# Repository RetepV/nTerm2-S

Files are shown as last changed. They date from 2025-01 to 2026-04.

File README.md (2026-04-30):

# nTerm2-S

> [!IMPORTANT]
> I have permanently decided to drop the CP2102 in favor of the FT231 as a USB<->Serial bridge. The CP2102 is just near impossible to solder with a soldering iron, and it was one of my objectives to not have to use hot air. As the rest of the design design is basically still the same, I decided to freeze this repository, keeping it like it is for whoever is interested, and start a new repository for the FT231 version. The design is working: if you make a board it should work, mine does.\
> \
> However, do note that I decided to move to the FT231 already before I made boards with the ESD USB protection circuit USBLC6-2SC6. It's in the latest design files here, but no boards were made and it has not been tested. However, that circuit is so uncomplicated, that I'm sure it will work fine. In worst case you can leave out the USBLC6-2SC6 and just connect pins 1-6 and 3-4. However, without ESD protection, I would suggest to connect the nTerm2-S through a cheap USB hub. No sense in jeopardising your USB ports.\
> \
> Also, I decided to add an RTC to nTerm2-S, and that's only in the FT231 version.\
> \
> Long story short, have look here for continuation of this project: https://github.com/RetepV/nTerm2-S-FT231

My rendition of the uTerm2-S by Just4Fun (https://hackaday.io/project/181583-uterm2-s-a-multi-emulation-color-rs232-terminal). This one is in SMD, and I hopefully made it easily hand-solderable for everyone (with maybe the exception of the CP2102). Obviously the 'n' in nTerm stands for 'nano.' :P

The nTerm2-S has a slightly more usable form the uTerm2-S, I think. Smaller and a little more usable when sitting permanently on a desk. And as an extra, it can switch between normal and cross (null-modem) from the software so that you wil never have to search for that null-modem cable ever again. It can also switch between RTS/CTS or DTR/DSR handshaking.

Supports RxD/TxD with RTS/CTS. Also supports DTR/DSR in a way. It is possible to switch the RTS/CTS lines to the DTR/DSR lines, using the ESP32's RTS/CTS support to manage the DTR/DSR. It's not really DTR/DSR, but as the ESP32 is a plenty fast enough DTE and only the DCE might be slow, it will work most of the times.

The nTerm2-S is ultimately based on the FABGL library and board design from Fabrizio Di Vittori. http://www.fabglib.org. However, I skipped Fabrizio's implementation and based my design on Just4Fun's uTerm2-S. https://j4f.info/uterm2-s

THIS IS A WORK IN PROGESS! I.E. UNLESS STATED AS WORKING, ASSUME THAT IT DOES NOT WORK! NO FIRMWARE HAS BEEN TESTED YET, AND AS THERE ARE SMALL DIFFERENCES IN GPIO ASSIGNMENTS, I DON'T EXPECT THE DEFAULT FABGL EXAMPLES TO WORK WITHOUT TWEAKS.

<sub><s>NOTE: The relay circuit with the bistable relays is directly out of the OMRON databook, and it allows me to switch the relay but use only power when switching (and some losses through the 470 resistor when switched on: 7mA continuous, which is a huge of a lot better than 30mA continuous when using a normal relay). That circuit sources the power from the input, which is connected to a GPIO. ESP32 GPIO pins can source 40mA and sink 28mA. According to the datasheet, the relay needs 100mW of power to switch. At 3V, that is 33mA, but we use 3.3V, so some 30mA. So when switching 'on', the ESP32 will need to source 30mA and settle at some 7mA (all theoretically, be advised). That is quite a lot, but still within spec. The ESP32 does not have to sink much, as the reverse current will go through the diode directly to ground.</s><sub>

<sub>It turned out that the ESP32 was not able to source enough power after all, so I have had to change the circuit somewhat. Now all the necessary power comes from the 5V Vbus and is switched through another transistor. I couldn't properly measure the current draw from the ESP32's GPIO port, but it looked as if it was some 4mA.</sub>

<sub>Progress! I received my fuses and did some real measurements. I used 3.3V, BAT45 (commit says 1N4148, but I was mistaken, they are BAT45's), BC337, 220u and 470 ohm on my bread board, and measured about 14mA max when switching, and 6.8mA continuous. I expected more than 14mA when switching, but maybe this relay is better than the specs? In any case, I decided to experiment with the C and R. I upped the C to 470uF, which seemed to make the switching more reliable. But more importantly, I increased the resistor in steps to see what the result would be. And found that I could go up to at least 3K9 before the switching would become unreliable. 10K was clearly too much, and I didn't try anything in between 3K9 and 10K. With 3K9, 0.88mA is drawn, and I find that good enough. The low current power led uses 3mA, and I keep that on all the time. 1mA is fine.</sub>

<sub>Created the gerbers for v0.1 and sent out to JLPCB. Jeez, it's cheap. 11 euro for 5 boards. Still had a bunch of warnings from the pins/vias of the USB-C connector and ESP32 footprints that I just could not resolve. Decided to take my chances, and JLCPCB accepted the gerbers and has actually already finished and posted the boards. So I expect the boards to be here in a few days. In the mean time, I've been doing some basic work and redesign for a version 2 of the nTerm2-S, with an SD card slot and psram, to make it more versatile (e.g. PC emulation). However, let's get this first version to work first, the objective is to have a terminal with software switchable null-modem.</sub>

<sub>After my v0.1 boards arrived I built one up. I did it in stages, starting with the CP2102 and then the power (I use the CP2102 in bus-powered mode). After much cursing, I got the CP2012 straight on the pads and it looked good under the microscope. I then added the power supply components and the USB-C port. No ESD protection yet. Doublechecked everything 10 times under the microscope, got out an old cheap USB hub (better to blow up the hub than my Macbook's port) and plugged the nTerm in. And Windows detected the CP2102 immediately, installed the drivers, and... success #1 was there!</sub>

<sub>I then added the ESP32. Could update its firmware. Success #2! Soldered the video DAC and VGA port (and fixed the ESP32). Success #3: we have video! Then populated the keyboard and mouse circuits. Success #4! After playing some Space Invaders, I populated the MAX3232 and hardwired the Rx and Tx together to do a loopback test. And we had success #5!</sub>

<sub>Then the problems started. After populating the relay circuits, I could not get them to switch. After lots of measuring and experimenting with an oscilloscope, I could only conclude that the ESP32 was simply not able to source a high enough voltage and that all my calculations and experiments apparently had been wrong. The switching voltage of the relay is 3V. But I found that the ESP32, in my setting, delivered only some 3.15V, and that goes through the BAT43W diode. The diode has a low voltage drop, but it's still something like 0.55V or more at 30mA, and that brings the operating voltage down to 2.61V. Switching one way (with a 1 on the GPIO), it means that the relay gets 2.61V, which is enough to switch it that way. But not the other way. The capacitor is charged with 2.61V. But when it discharges, it discharges through the BC817, which adds another voltage drop of somewhere between 0.1 and 0.4 volt. And now, with worst case 2.21V we are just around the minimum set voltage for the relay, which is 2.25V typical. The charge in the capacitor is not enough to deliver enough energy in that case.</sub>

<sub>So now I had to experiment with the board itself and found that what I could do was to change the input diode to a transistor in common collector (emitter follower) configuration, and basically buffer ESP32's GPIO. So I replaced the BAT43 diode with a BC817 transistor, with collector tied to 5V and emitter tied to the input of the circuit. This brings the voltage into the circuit up to the 3.15V that the ESP32 was outputting (voltage drop of the transistor is negated by feeding it 5V). And after fiddling a bit with resistor and capacitor values I got it all working reliably.</sub>

<sub>I left it at that, it was working now with minimal changes and no inrease in cost.</sub>

<sub>Problems encountered and fixed:</sub>

<sub>1. The CP2102 was really hard to solder, even using hot air. I am looking into the FT231 as a much easier to solder alternative. But the FT231 seems to have more driver issues than the CP2102 (which has none, as far as I know). As an alternative, it might help to increase the size of the pads.
2. The ESD protection diodes were much tinier than I thought. Looking at the PCB in Kicad, they didn't seem so small. :) So I should try to find larger diodes.
3. I thought I had an ESP32 lying around, but it turned out that I only had one that was soldered to a breakout board. So I decided to desolder that, instead of wait for new ones to arrive. Well, that did not go too well. I ripped off one of the castellated pads, one which is used for hSync. So no video. But I a not defeated so easily, so I lifted the cap off the module, soldered a wire directly to the ESP32 chip and ran it to the HSYNC line. Win! .;) I could start some serious testing
4. The relay circuits don't work. Had to redesign somewhat.
5. I accidentally used the J-leg footprint for the IM41's instead of the Gullwing footprint.
6. Many of the large capacitor's footprints were simply wrong and I had to solder one vertically.
7. I used tantalum caps in the relay circuits, but there's no reason to not use the much cheaper normal electrolytic caps.
</sub>

<sub>After a fixing all of the above, and refactoring a few things on the board, version v0.6 was arrived at. And once again I had boards made by JCPCB. 17 euro for 5 boards. Still cheap, but no discount for me this time. The new boards arrived in record time, and I went to populate one.<s/ub>

<sub>Observations:</sub>

<sub>1. Still have one capacitor's footprint wrong. Although this I was able to fit it horizontally at least.
2. CP2102 solders much easier with the larger sized pads. But it still is fiddly to hand-solder a QFN-28 chip. I wish Silicon Labs would make a QFP-28 version.
3. The board is detected by my Macbook, but can't communicate with it. My Windows machine is luckily able to communicate and flash, but it doesn't seem too happy about it all. What's going on? Turns out that I had chosen ESD diodes for their size, but did not realize that with their size also comes a high capacity of some 100pF. And that's enough to mess up the USB communications. So it's back to the ol' drawing board here. Removing the ESD diodes makes USB work again on all my machines. But i want them, so we'll need a new revision already. 
4. My new relay circuits work! Flawlessly even!
5. Why did I not add an option to keep the amplifier circuit unpopulated and have a line-out instead of a speaker-out? Or why not both options, selectable throguh solder bridges?</sub>

<sub>Apart from these issues, nTerm2-S v0.5 works!</sub>

<sub>v0.1 vs v0.5:</sub>




<sub>Testing v0.5</sub>



<sub>I just finished the v0.6 design with fixes for all of the above. That would be the final design, with only a slight feature creep (being able to omit/bypass the speaker amplifier). Now we need software...</sub>

This design is available under GPL License V3. This means that I DO NOT release it for commercial use, unless with my explicit written and signed consent. Please contact me if you have commercial questions.

uTerm2-S: https://hackaday.io/project/181583-uterm2-s-a-multi-emulation-color-rs232-terminal  
fabgl: http://www.fabglib.org/, https://github.com/fdivitto/FabGL

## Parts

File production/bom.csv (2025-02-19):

Designator | Footprint | Quantity | Value | LCSC Part #
C1 | CP_Elec_6.3x7.7 | 1 | 220u
C10, C11, C12, C19, C21, C8, C9 | CP_EIA-3216-18_Kemet-A_Pad1.58x1.35mm_HandSolder | 7 | 0.1u
C13 | CP_EIA-6032-28_Kemet-C_Pad2.25x2.35mm_HandSolder | 1 | 10u/25v
C14 | CP_EIA-3216-18_Kemet-A_Pad1.58x1.35mm_HandSolder | 1 | 0.1u/25v
C15, C16, C22, C24 | 0603 | 4 | 1n
C17 | CP_EIA-3216-18_Kemet-A_Pad1.58x1.35mm_HandSolder | 1 | 1u
C18 | CP_EIA-6032-28_Kemet-C_Pad2.25x2.35mm_HandSolder | 1 | 100u
C2 | CP_Elec_6.3x7.7 | 1 | 100u
C20 | CP_EIA-3528-21_Kemet-B_Pad1.50x2.35mm_HandSolder | 1 | 10u
C23 | CP_EIA-6032-28_Kemet-C_Pad2.25x2.35mm_HandSolder | 1 | 100u/25V
C25, C26, C27 | CP_Elec_6.3x7.7 | 3 | 470u
C3 | 0805 | 1 | 10u
C4 | 0603 | 1 | 47n
C5 | 0603 | 1 | 2.2n
C6, C7 | 0603 | 2 | 100n
D1, D2 | D_SMA | 2 | P4SMAJ5.0CA
D10, D5, D6, D7, D8, D9 | D_SOD-123 | 6 | BAT43W-V
D11, D12 | DIALIGHT_LED_3MM_DOUBLE | 2 | LED_Dual_AKAK
D3 | Nexperia_CFP3_SOD-123W | 1 | 1N5819
D4 | DIALIGHT_LED_3MM_SINGLE | 1 | LED
J1 | DSUB-15-HD_Female_Horizontal_P2.29x1.98mm_EdgePinOffset8.35mm_Housed_MountingHolesOffset10.89mm | 1 | VGA
J2 | Connector_Mini-DIN_Female_6Pin_2rows | 1 | Keyboard
J3 | Connector_Mini-DIN_Female_6Pin_2rows | 1 | Mouse
J4 | Jack_3.5mm_Ledino_KB3SPRS_Horizontal | 1 | Speaker
J5 | DSUB-9_Male_Horizontal_P2.77x2.84mm_EdgePinOffset4.94mm_Housed_MountingHolesOffset7.48mm | 1 | DE9_Plug_MountingHoles
J6 | USB_C_Receptacle_Molex_213716-0001 | 1 | USB_C_Receptacle_USB2.0_16P
K1, K2, K3 | Relay_DPDT_AXICOM_IMSeries_Gullwing | 3 | IM41 3V
Q1, Q2, Q3, Q4, Q5 | SOT-23 | 5 | BC817
R1, R3, R5 | 0603 | 3 | 820
R10, R13, R14, R9 | 0603 | 4 | 2K2
R11, R12, R15, R16 | 0603 | 4 | 120
R17 | 0603 | 1 | 10
R18, R19, R22, R23 | 0603 | 4 | 10K
R2, R4, R6 | 0603 | 3 | 390
R20 | 0603 | 1 | 150
R21 | 0603 | 1 | 270
R24, R25, R28 | 0603 | 3 | 470
R26, R29 | 0603 | 2 | 12K
R27 | 0603 | 1 | 5K
R30, R35, R36, R37, R38 | 0603 | 5 | 2K
R31 | 0603 | 1 | 4.7K
R32, R33, R34 | 0603 | 3 | 3K9
R39 | 0603 | 1 | 22.1K
R40 | 0603 | 1 | 47.5K
R7, R8 | 0603 | 2 | 220
SW1 | SW_Tactile_SPST_Angled_PTS645Vx58-2LFS | 1 | IO0
SW2 | SW_Tactile_SPST_Angled_PTS645Vx58-2LFS | 1 | RESET
SW3 | SW_Tactile_SPST_Angled_PTS645Vx58-2LFS | 1 | DEFAULTS
U1 | ESP32-WROOM-32 | 1 | ESP32-WROOM-32
U2 | SOIC-8_3.9x4.9mm_P1.27mm | 1 | LM386
U3 | SOIC-16_3.9x9.9mm_P1.27mm | 1 | MAX3232E
U4 | QFN-28-1EP_5x5mm_P0.5mm_EP3.35x3.35mm | 1 | CP2102N-Axx-xQFN28
U5 | SOT-223-3_TabPin2 | 1 | NCP1117-3.3_SOT223

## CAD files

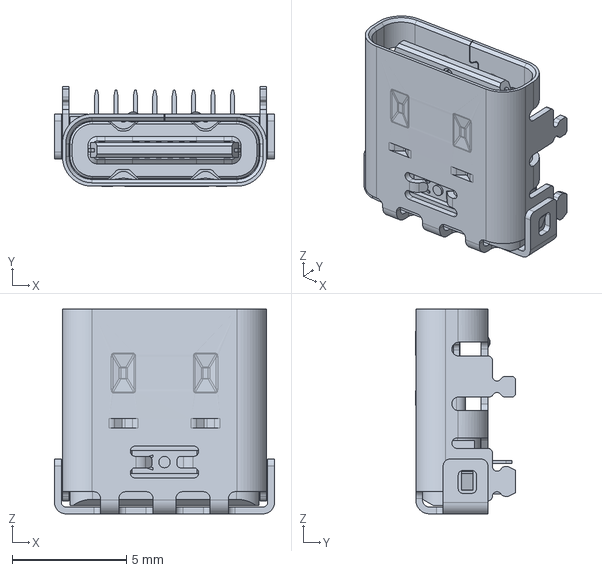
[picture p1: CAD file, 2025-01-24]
footprints/2137160001.stp
9.64 x 4.36 x 8.97 mm

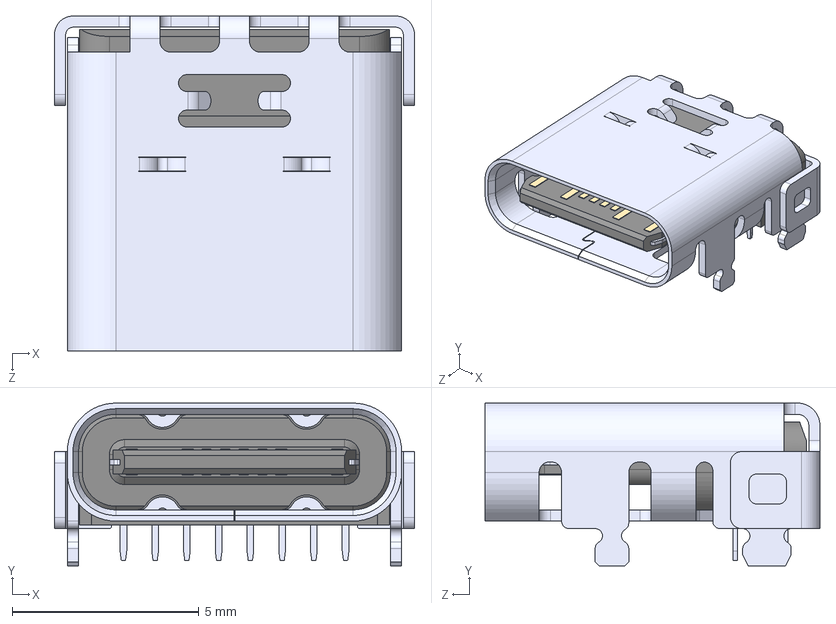
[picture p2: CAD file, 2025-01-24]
footprints/2137160001/2137160001.step
9.64 x 4.36 x 8.97 mm

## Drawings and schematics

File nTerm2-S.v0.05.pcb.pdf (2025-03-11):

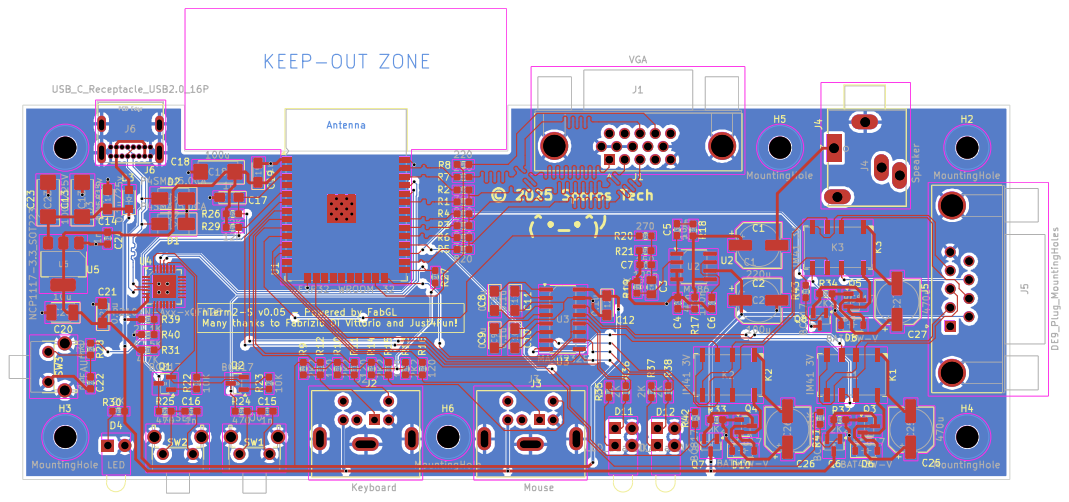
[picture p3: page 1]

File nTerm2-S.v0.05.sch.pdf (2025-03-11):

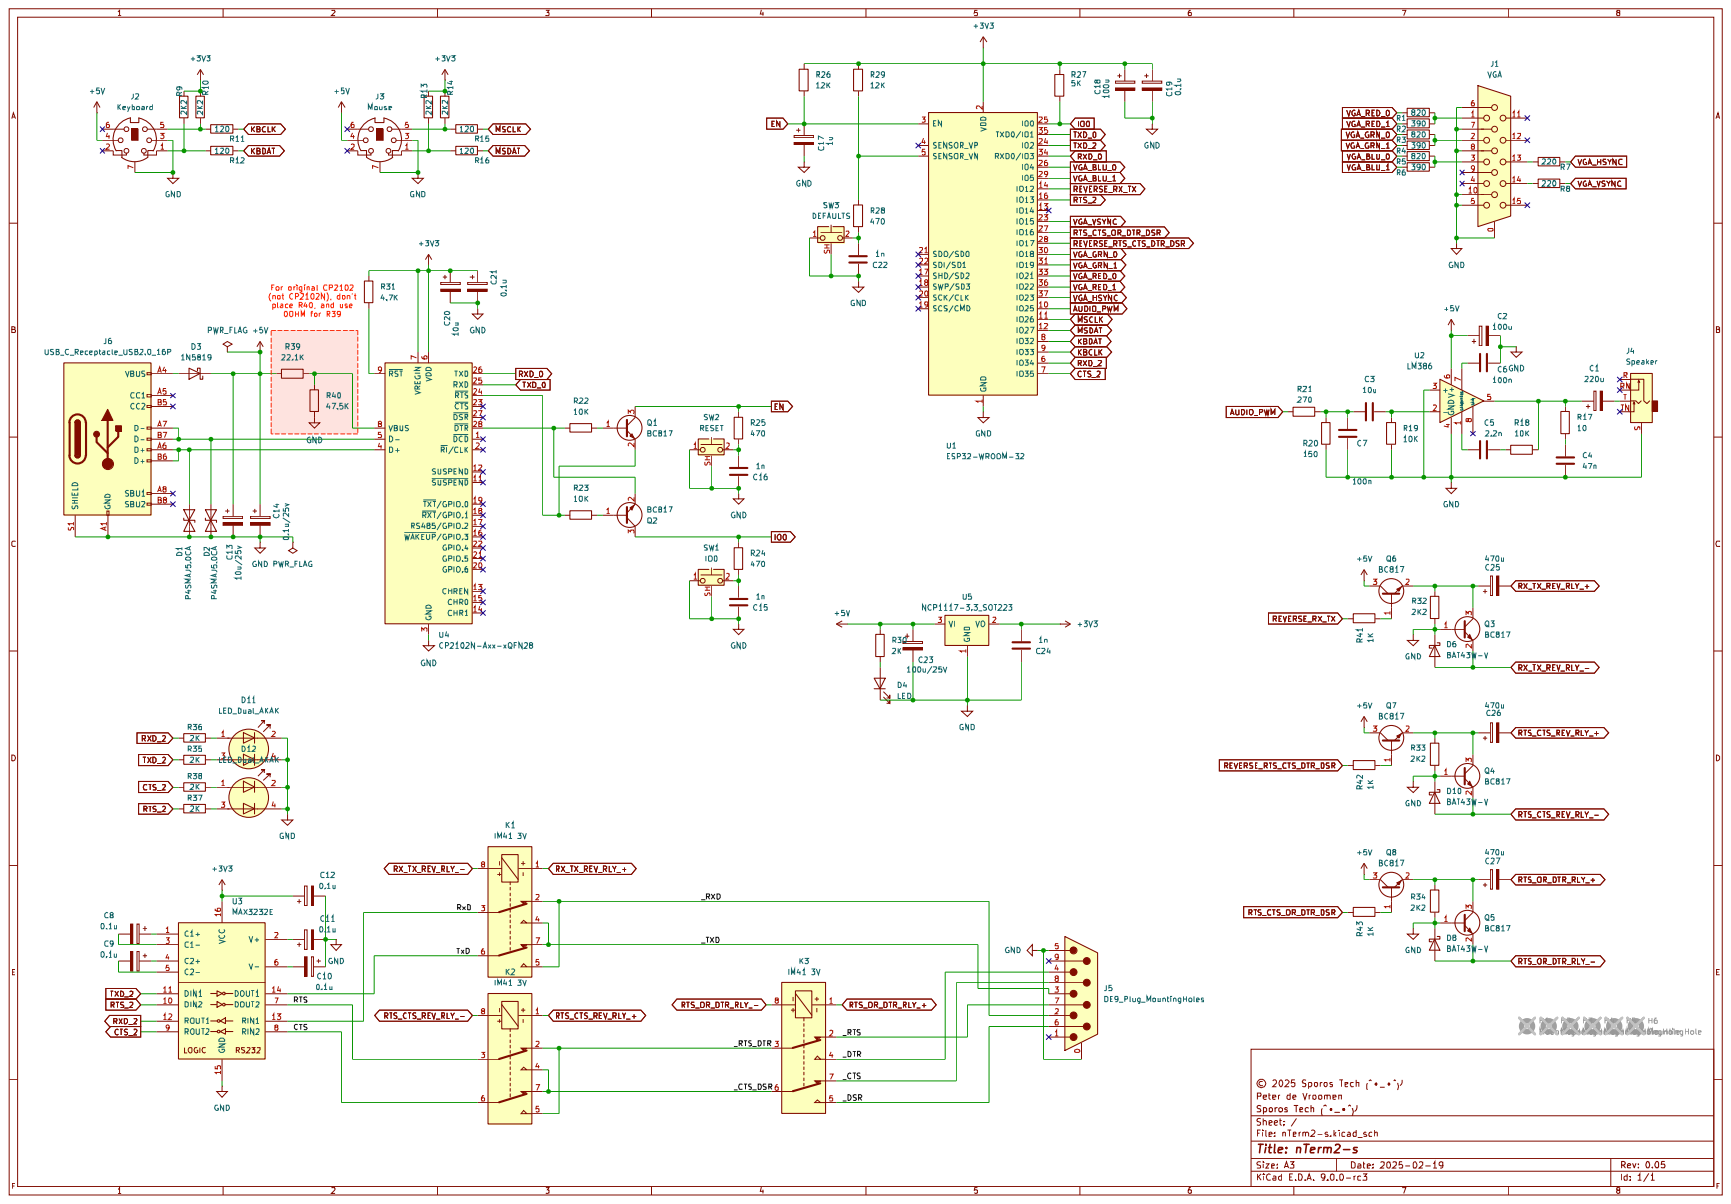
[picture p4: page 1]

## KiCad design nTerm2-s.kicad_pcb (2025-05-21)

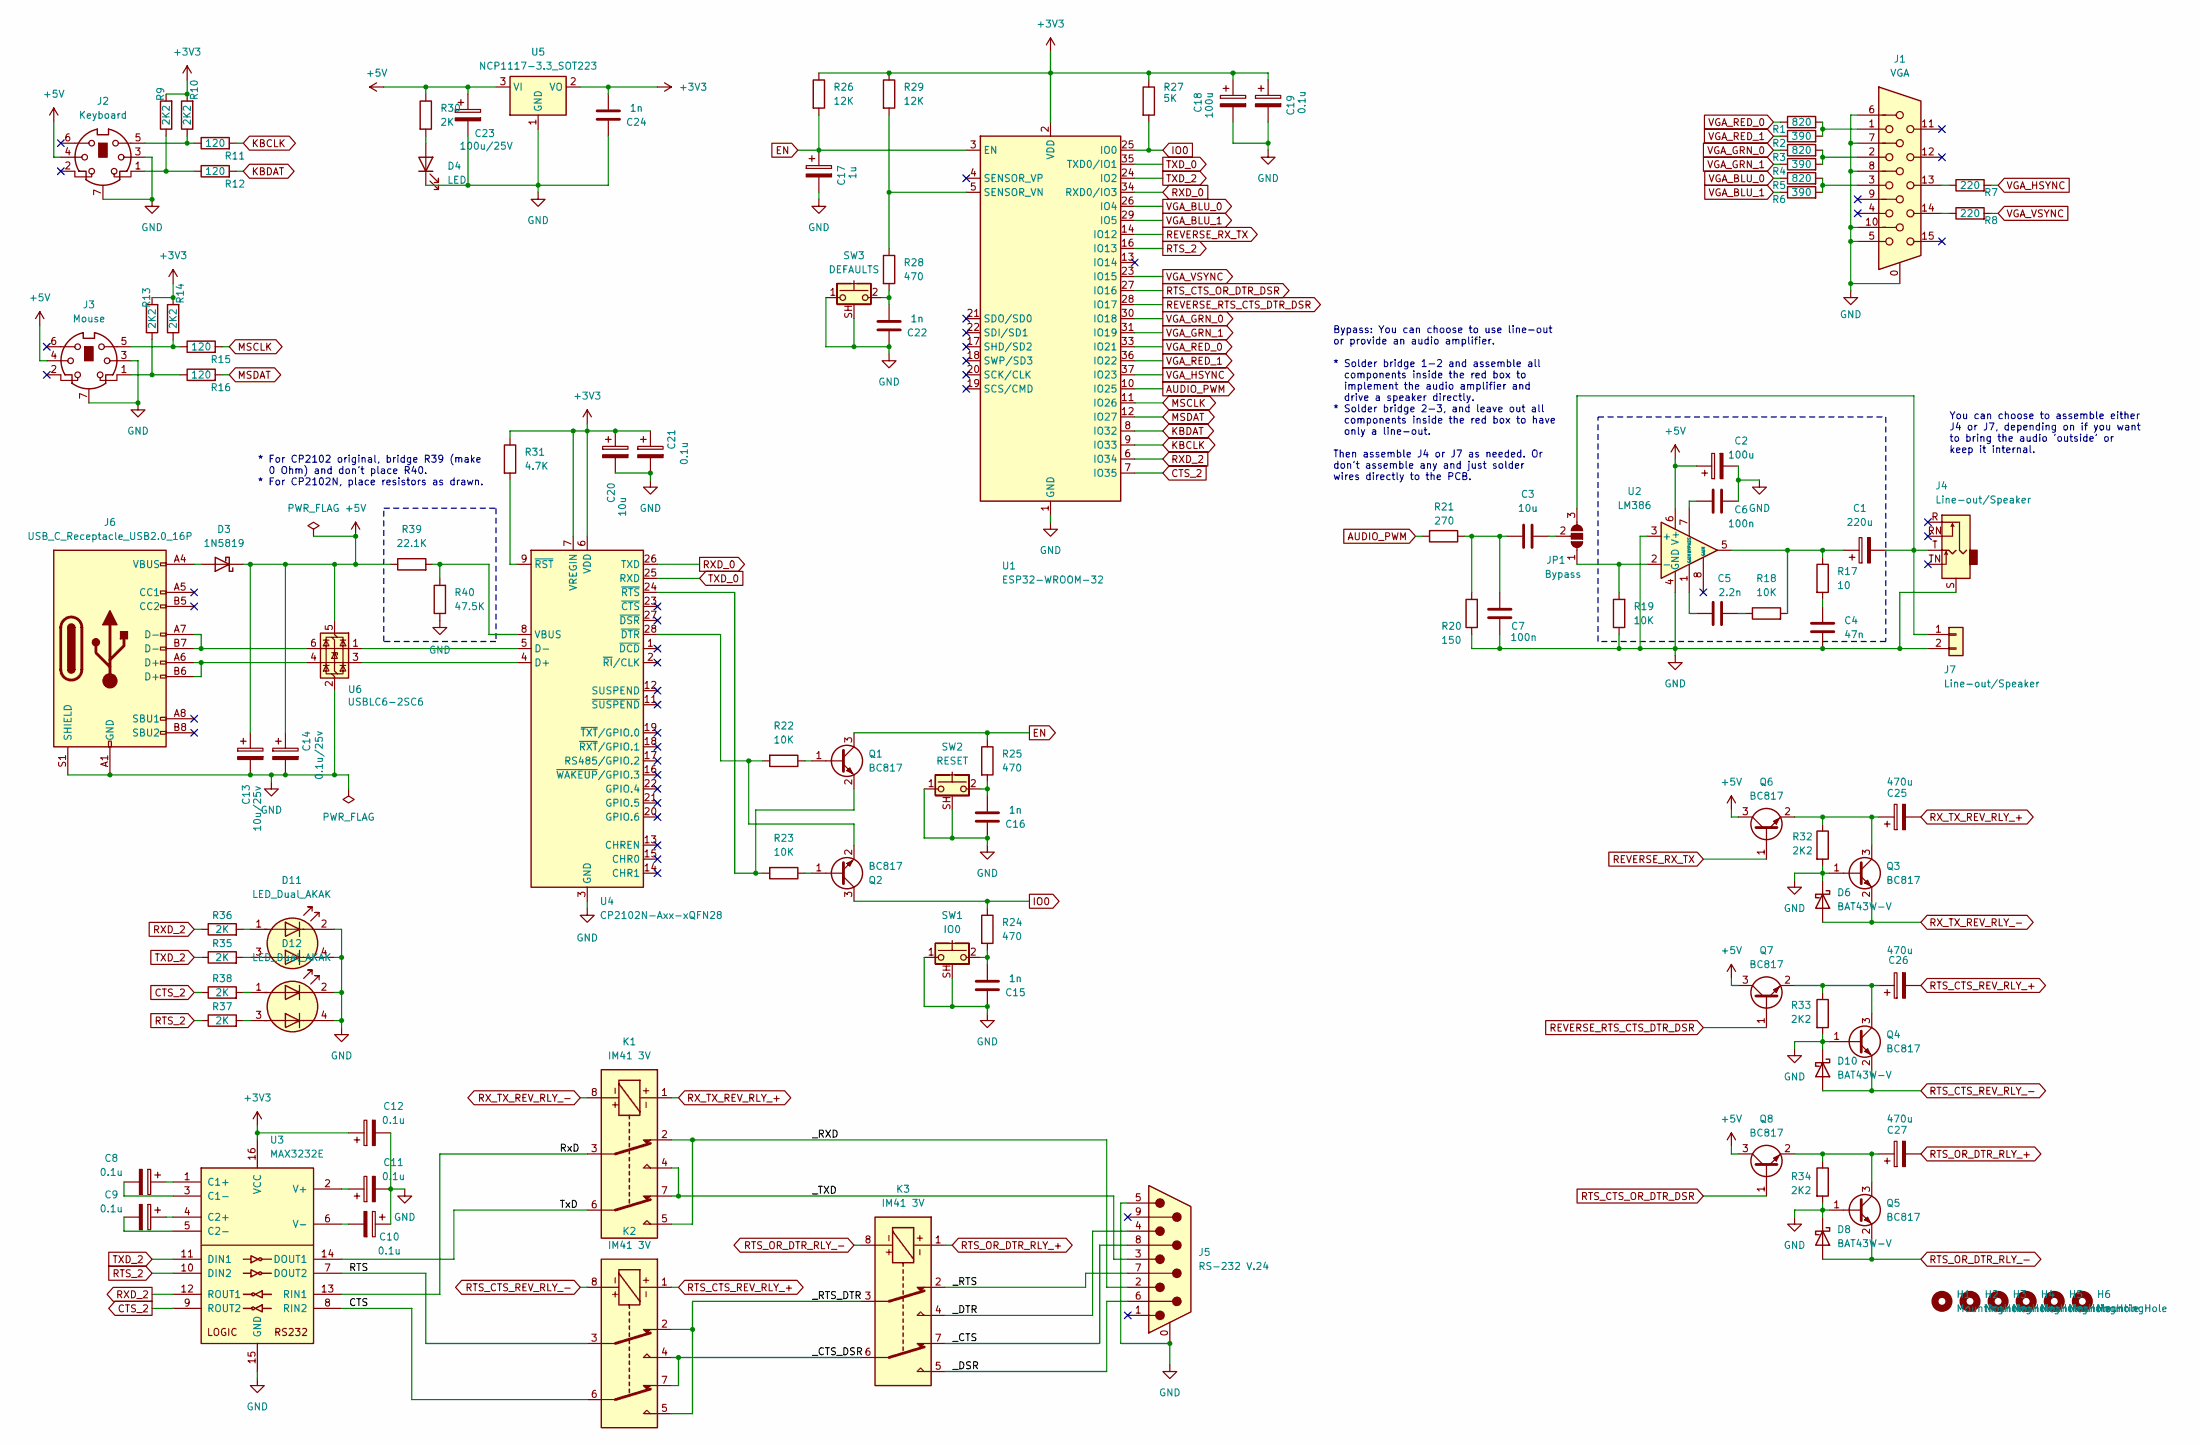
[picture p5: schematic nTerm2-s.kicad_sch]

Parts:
C1: 220u; CP_Elec_6.3x7.7
C2: 100u; CP_Elec_6.3x7.7
C3: 10u; C_0805_2012Metric_Pad1.18x1.45mm_HandSolder
C4: 47n; C_0603_1608Metric_Pad1.08x0.95mm_HandSolder
C5: 2.2n; C_0603_1608Metric_Pad1.08x0.95mm_HandSolder
C6, C7: 100n; C_0603_1608Metric_Pad1.08x0.95mm_HandSolder
C8, C9, C10, C11, C12, C19, C21: 0.1u; CP_EIA-3216-18_Kemet-A_Pad1.58x1.35mm_HandSolder
C13: 10u/25v; CP_EIA-6032-28_Kemet-C_Pad2.25x2.35mm_HandSolder
C14: 0.1u/25v; CP_EIA-3216-18_Kemet-A_Pad1.58x1.35mm_HandSolder
C15, C16, C22, C24: 1n; C_0603_1608Metric_Pad1.08x0.95mm_HandSolder
C17: 1u; CP_EIA-3216-18_Kemet-A_Pad1.58x1.35mm_HandSolder
C18: 100u; CP_EIA-6032-28_Kemet-C_Pad2.25x2.35mm_HandSolder
C20: 10u; CP_EIA-3528-21_Kemet-B_Pad1.50x2.35mm_HandSolder
C23: 100u/25V; CP_EIA-7343-30_AVX-N_Pad2.25x2.55mm_HandSolder
C25, C26, C27: 470u; CP_Elec_6.3x7.7
D3: 1N5819; Nexperia_CFP3_SOD-123W
D4: LED; DIALIGHT_LED_3MM_SINGLE
D6, D8, D10: BAT43W-V; D_SOD-123
D11, D12: LED_Dual_AKAK; DIALIGHT_LED_3MM_DOUBLE
H1, H2, H3, H4, H5, H6: MountingHole; MountingHole_3.2mm_M3
J1: VGA; DSUB-15-HD_Female_Horizontal_P2.29x1.98mm_EdgePinOffset3.03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
J2: Keyboard; Connector_Mini-DIN_Female_6Pin_2rows
J3: Mouse; Connector_Mini-DIN_Female_6Pin_2rows
J4: Line-out/Speaker; Jack_3.5mm_Ledino_KB3SPRS_Horizontal-alt
J5: RS-232 V.24; DSUB-9_Male_Horizontal_P2.77x2.84mm_EdgePinOffset4.94mm_Hou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
J6: USB_C_Receptacle_USB2.0_16P; USB_C_Receptacle_Molex_213716-0001
J7: Line-out/Speaker; PinHeader_1x02_P2.54mm_Vertical
JP1: Bypass; SolderJumper-3_P1.3mm_Open_RoundedPad1.0x1.5mm_NumberLabels
K1, K2, K3: IM41 3V; Relay_DPDT_AXICOM_IMSeries_Gullwing
Q1, Q2, Q3, Q4, Q5, Q6, Q7, Q8: BC817; SOT-23
R1, R3, R5: 820; R_0603_1608Metric_Pad0.98x0.95mm_HandSolder
R2, R4, R6: 390; R_0603_1608Metric_Pad0.98x0.95mm_HandSolder
R7, R8: 220; R_0603_1608Metric_Pad0.98x0.95mm_HandSolder
R9, R10, R13, R14, R32, R33, R34: 2K2; R_0603_1608Metric_Pad0.98x0.95mm_HandSolder
R11, R12, R15, R16: 120; R_0603_1608Metric_Pad0.98x0.95mm_HandSolder
R17: 10; R_0603_1608Metric_Pad0.98x0.95mm_HandSolder
R18, R19, R22, R23: 10K; R_0603_1608Metric_Pad0.98x0.95mm_HandSolder
R20: 150; R_0603_1608Metric_Pad0.98x0.95mm_HandSolder
R21: 270; R_0603_1608Metric_Pad0.98x0.95mm_HandSolder
R24, R25, R28: 470; R_0603_1608Metric_Pad0.98x0.95mm_HandSolder
R26, R29: 12K; R_0603_1608Metric_Pad0.98x0.95mm_HandSolder
R27: 5K; R_0603_1608Metric_Pad0.98x0.95mm_HandSolder
R30, R35, R36, R37, R38: 2K; R_0603_1608Metric_Pad0.98x0.95mm_HandSolder
R31: 4.7K; R_0603_1608Metric_Pad0.98x0.95mm_HandSolder
R39: 22.1K; R_0603_1608Metric_Pad0.98x0.95mm_HandSolder
R40: 47.5K; R_0603_1608Metric_Pad0.98x0.95mm_HandSolder
SW1: IO0; SW_Tactile_SPST_Angled_PTS645Vx58-2LFS-alt
SW2: RESET; SW_Tactile_SPST_Angled_PTS645Vx58-2LFS-alt
SW3: DEFAULTS; SW_Tactile_SPST_Angled_PTS645Vx58-2LFS-alt
U1: ESP32-WROOM-32
U2: LM386; SOIC-8_3.9x4.9mm_P1.27mm
U3: MAX3232E; SOIC-16_3.9x9.9mm_P1.27mm
U4: CP2102N-Axx-xQFN28; QFN-28-1EP_5x5mm_P0.5mm_EP3.35x3.35mm_handsolder
U5: NCP1117-3.3_SOT223; SOT-223-3_TabPin2
U6: USBLC6-2SC6; SOT-23-6

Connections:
+3V3: C12.1, C18.1, C19.1, C20.1, C21.1, C24.1, R9.2, R10.2, R13.2, R14.2, R26.1, R27.1, R29.1, R31.1, U1.2 (VDD), U3.16 (VCC), U4.6 (VDD), U4.7 (VREGIN), U5.2 (VO)
+5V: C2.1, C13.1, C14.1, C23.1, D3.1 (K), J2.4, J3.4, Q6.3 (C), Q7.3 (C), Q8.3 (C), R30.1, R39.1, U2.6 (V+), U5.3 (VI), U6.5 (VBUS)
/CTS: K2.6, U3.8 (RIN2)
/RTS: K2.3, U3.7 (DOUT2)
/RxD: K1.3, U3.13 (RIN1)
/TxD: K1.6, U3.14 (DOUT1)
/_CTS: J5.8, K3.7
/_CTS_DSR: K2.4, K2.7, K3.6
/_DSR: J5.6, K3.5
/_DTR: J5.4, K3.4
/_RTS: J5.7, K3.2
/_RTS_DTR: K2.2, K2.5, K3.3
/_RXD: J5.2, K1.2, K1.5
/_TXD: J5.3, K1.4, K1.7
AUDIO_PWM: R21.2, U1.10 (IO25)
CTS_2: R38.1, U1.7 (IO35), U3.9 (ROUT2)
EN: C17.1, Q1.3 (C), R25.1, R26.2, U1.3 (EN)
GND: C2.2, C4.2, C6.2, C7.1, C10.1, C11.2, C12.2, C13.2, C14.2, C15.2, C16.2, C17.2, C18.2, C19.2, C20.2, C21.2, C22.2, C23.2, C24.2, D4.2 (K), D6.1 (K), D8.1 (K), D10.1 (K), D11.2 (K1), D11.4 (K2), D12.2 (K1), D12.4 (K2), J1.0, J1.5, J1.6, J1.7, J1.8, J1.10, J2.3, J2.7, J3.3, J3.7, J4.S, J5.0 (PAD), J5.5, J6.A1 (GND), J6.A12 (GND), J6.B1 (GND), J6.B12 (GND), J6.S1 (SHIELD), J7.2, Q3.1 (B), Q4.1 (B), Q5.1 (B), R19.1, R20.1, R32.2, R33.2, R34.2, R40.1, SW1.1, SW1.SH (B), SW2.1, SW2.SH (B), SW3.1, SW3.SH (B), U1.1 (GND), U1.15 (GND), U1.38 (GND), U1.39 (GND), U2.3 (+), U2.4 (GND), U3.15 (GND), U4.3 (GND), U4.29 (GND), U5.1 (GND), U6.2 (GND)
IO0: Q2.3 (C), R24.1, R27.2, U1.25 (IO0)
KBCLK: R11.2, U1.9 (IO33)
KBDAT: R12.2, U1.8 (IO32)
MSCLK: R15.2, U1.11 (IO26)
MSDAT: R16.2, U1.12 (IO27)
unnamed: C1.1, R17.1, R18.2, U2.5
unnamed: C3.1, C7.2, R20.2, R21.1
unnamed: C4.1, R17.2
unnamed: C5.1, U2.1 (GAIN)
unnamed: C5.2, R18.1
unnamed: C15.1, R24.2, SW1.2
unnamed: C16.1, R25.2, SW2.2
unnamed: C22.1, R28.2, SW3.2
unnamed: D3.2 (A), J6.A4 (VBUS), J6.A9 (VBUS), J6.B4 (VBUS), J6.B9 (VBUS)
unnamed: D4.1 (A), R30.2
unnamed: D11.1 (A1), R36.2
unnamed: D11.3 (A2), R35.2
unnamed: D12.1 (A1), R38.2
unnamed: D12.3 (A2), R37.2
unnamed: J1.1, R1.2, R2.2
unnamed: J1.2, R3.2, R4.2
unnamed: J1.3, R5.2, R6.2
unnamed: J1.13, R7.1
unnamed: J1.14, R8.1
unnamed: J2.1, R9.1, R12.1
unnamed: J2.5, R10.1, R11.1
unnamed: J3.1, R13.1, R16.1
unnamed: J3.5, R14.1, R15.1
unnamed: J6.A6 (D+), J6.B6 (D+), U6.4 (I/O2)
unnamed: J6.A7 (D-), J6.B7 (D-), U6.6 (I/O1)
unnamed: C1.2, J4.T, J7.1, JP1.3 (B)
unnamed: JP1.1 (A), R19.2, U2.2 (-)
unnamed: C3.2, JP1.2 (C)
unnamed: Q1.1 (B), R22.1
unnamed: Q1.2 (E), R23.2, U4.24 (~RTS)
unnamed: Q2.1 (B), R23.1
unnamed: Q2.2 (E), R22.2, U4.28 (~DTR)
unnamed: C25.1, Q3.3 (C), Q6.2 (E), R32.1
unnamed: C26.1, Q4.3 (C), Q7.2 (E), R33.1
unnamed: C27.1, Q5.3 (C), Q8.2 (E), R34.1
unnamed: R28.1, R29.2, U1.5 (SENSOR_VN)
unnamed: C6.1, U2.7 (BYPASS)
unnamed: C8.1, U3.1 (C1+)
unnamed: C8.2, U3.3 (C1-)
unnamed: C9.1, U3.4 (C2+)
unnamed: C9.2, U3.5 (C2-)
unnamed: C11.1, U3.2 (V+)
unnamed: C10.2, U3.6 (V-)
unnamed: U4.4 (D+), U6.3 (I/O2)
unnamed: U4.5 (D-), U6.1 (I/O1)
unnamed: R39.2, R40.2, U4.8 (VBUS)
unnamed: R31.2, U4.9 (~RST)
REVERSE_RTS_CTS_DTR_DSR: Q7.1 (B), U1.28 (IO17)
REVERSE_RX_TX: Q6.1 (B), U1.14 (IO12)
RTS_2: R37.1, U1.16 (IO13), U3.10 (DIN2)
RTS_CTS_OR_DTR_DSR: Q8.1 (B), U1.27 (IO16)
RTS_CTS_REV_RLY_+: C26.2, K2.1
RTS_CTS_REV_RLY_-: D10.2 (A), K2.8, Q4.2 (E)
RTS_OR_DTR_RLY_+: C27.2, K3.1
RTS_OR_DTR_RLY_-: D8.2 (A), K3.8, Q5.2 (E)
RXD_0: U1.34 (RXD0/IO3), U4.26 (TXD)
RXD_2: R36.1, U1.6 (IO34), U3.12 (ROUT1)
RX_TX_REV_RLY_+: C25.2, K1.1
RX_TX_REV_RLY_-: D6.2 (A), K1.8, Q3.2 (E)
TXD_0: U1.35 (TXD0/IO1), U4.25 (RXD)
TXD_2: R35.1, U1.24 (IO2), U3.11 (DIN1)
VGA_BLU_0: R5.1, U1.26 (IO4)
VGA_BLU_1: R6.1, U1.29 (IO5)
VGA_GRN_0: R3.1, U1.30 (IO18)
VGA_GRN_1: R4.1, U1.31 (IO19)
VGA_HSYNC: R7.2, U1.37 (IO23)
VGA_RED_0: R1.1, U1.33 (IO21)
VGA_RED_1: R2.1, U1.36 (IO22)
VGA_VSYNC: R8.2, U1.23 (IO15)

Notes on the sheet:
You can choose to assemble either J4 or J7, depending on if you want to bring the audio 'outside' or keep it internal.
* For CP2102 original, bridge R39 (make 0 Ohm) and don't place R40. * For CP2102N, place resistors as drawn.
Bypass: You can choose to use line-out or provide an audio amplifier. * Solder bridge 1-2 and assemble all components inside the red box to implement the audio amplifier and drive a speaker directly. * Solder bridge 2-3, and leave out all components inside the red box to have only a line-out. Then 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

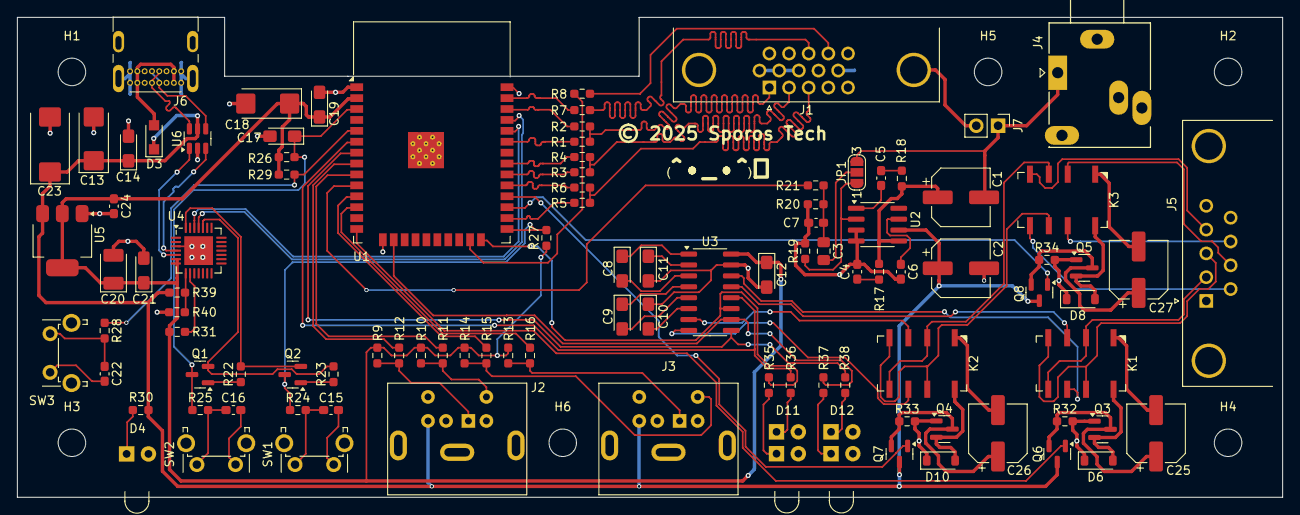
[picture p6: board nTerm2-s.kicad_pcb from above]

Board: 2 copper layers, 147.3 x 55.9 mm, 108 parts (0 on the bottom side), 92 nets.

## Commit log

2025-01-15 Initial WIP commit.
    [nTerm2-s-v0.0.kicad_pcb, nTerm2-s.kicad_pcb, nTerm2-s.kicad_sch]
2025-01-17 Improvements: - Move 'defaults' button to side, to create space for extra mounting holes. - Change type of USB pug to one with through-hole mounts for extra strength. - Fix audio plug. - Keep some di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
    [nTerm2-s.kicad_pcb, nTerm2-s.kicad_sch]
2025-01-17 Add PDF of schematic for easier viewing.
2025-01-19 Made board smaller for easier fitting in enclosure (150x55 or so). Many fixes. All vias are on 1.27 grid. USB-C ocnnector. VGA signal lines all same length, hopefully helping to give good video outpu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
    [nTerm2-s.kicad_pcb, nTerm2-s.kicad_sch]
2025-01-24 * Final details sorted. Hopefully I've got it all now. * Generated gerbers and sent to JLCPCB for boards to be made. * Fuses for my Fluke 175 multimeter arrived. Experimented with the relay driving c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
    [2137160001.step, 2137160001.stp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]
2025-01-29 Update wrong footprint for relays K1..K3.
    [nTerm2-s.kicad_pcb, nTerm2-s.kicad_sch]
2025-01-29 Fix all tantalum capacitor sizes.
    [nTerm2-s.kicad_pcb, nTerm2-s.kicad_sch]
2025-01-29 Some small replacements, doublechecked size of tiny ESD protectors, but they are really *tiny*. Set them further apart, so maybe they are easier to solder this way.
    [nTerm2-s.kicad_pcb, nTerm2-s.kicad_sch]
2025-01-29 Use other TVS protection diodes, with a hand-solderable size.
    [nTerm2-s.kicad_pcb, nTerm2-s.kicad_sch]
2025-02-04 More small improvements to layout.
    [nTerm2-s.kicad_pcb, nTerm2-s.kicad_sch]
2025-02-24 nTerm2-S v0.05 - New PCBs ordered.
    [nTerm2-s-BOM.csv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]
2025-03-11 Fix some small things (Forgot to update version in the .sch file). Create PDFs. Update a few backups.
    [nTerm2-s.kicad_sch]
2025-03-17 V0.06 - Use USBLC6-2 for ESD protection, instead of those big TVS diodes. Those big TVS diodes were a bad choice, they have far too high a capacity for USB 2.0 use. Removed resistors from the bases o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
    [nTerm2-s.kicad_pcb, nTerm2-s.kicad_sch]
2025-03-17 Update capacitor footprint to larger size.
    [nTerm2-s.kicad_pcb, nTerm2-s.kicad_sch]
2025-03-18 Hide the silk screen Hx designations of the mounting holes... :)
    [nTerm2-s.kicad_pcb]
2025-05-21 Some small updates, a fix, and exported all libraries into the project, for distribution.
    [nTerm2-s.kicad_pcb, nTerm2-s.kicad_sch]
2026-04-30 Revise troubleshooting section for relay circuit issues
    Clarified issues with relay circuits and ESP32 voltage sourcing. Updated troubleshooting steps and solutions for better reliability.
2026-04-30 Revise relay circuit explanation and solutions
    Clarified issues with relay circuit and voltage drops. Updated solution details for using a BC817 transistor to improve circuit performance.
2026-04-30 Revise README with circuit modification details
    Updated the explanation of the circuit modifications made to improve relay switching performance, including details on replacing the BAT43 diode with a BC817 transistor and the resulting voltage chan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
2026-04-30 Fix repeated content and clarify relay circuit troubleshooting
    Corrected repeated sections and improved clarity on the relay circuit issues and solutions.

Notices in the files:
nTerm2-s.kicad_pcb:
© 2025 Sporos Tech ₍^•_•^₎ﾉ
